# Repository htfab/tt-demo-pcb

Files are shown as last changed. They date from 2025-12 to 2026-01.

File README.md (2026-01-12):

# TinyTapeout Demo Board

Demo board for TinyTapeout ASICs

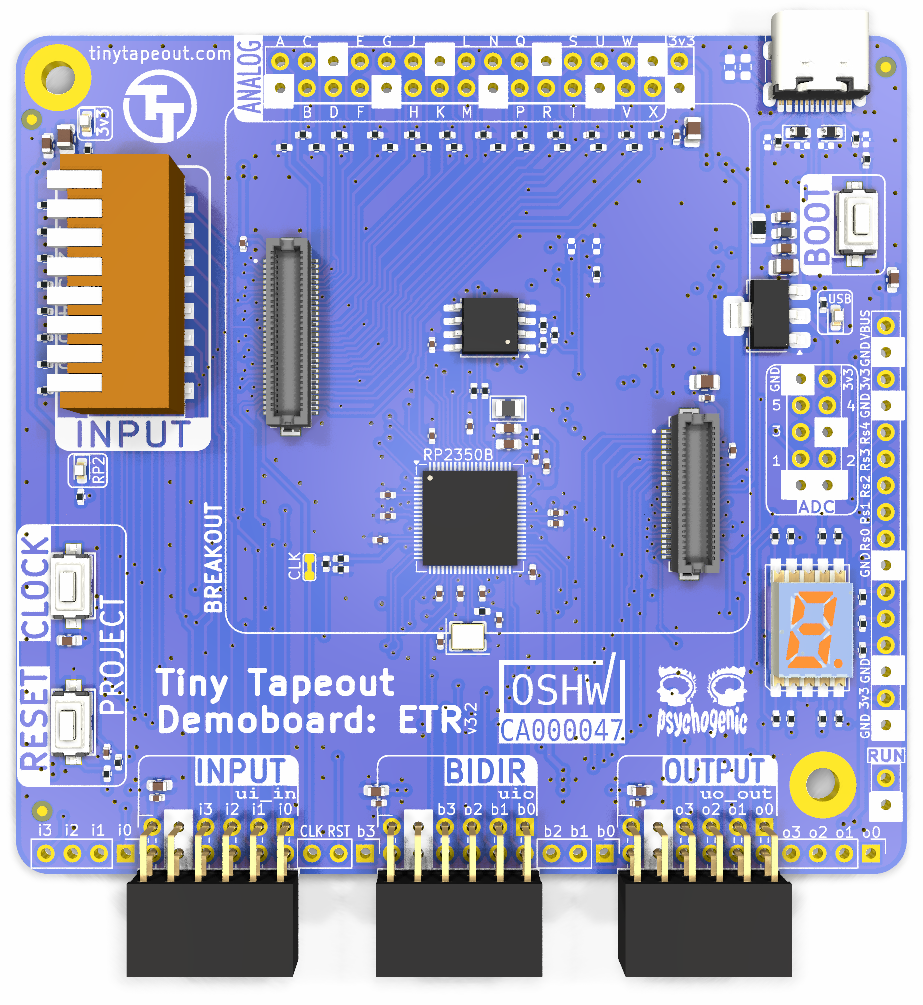
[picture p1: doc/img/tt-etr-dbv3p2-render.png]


These demonstration PCBs allow you to interact with [TinyTapeout](https://tinytapeout.com/) projects in 3 ways:

  * directly, using the input DIP switches and 7-segment display;
  * via breadboard or extension boards through PMODs; or
  * by interacting through the on-board RP2

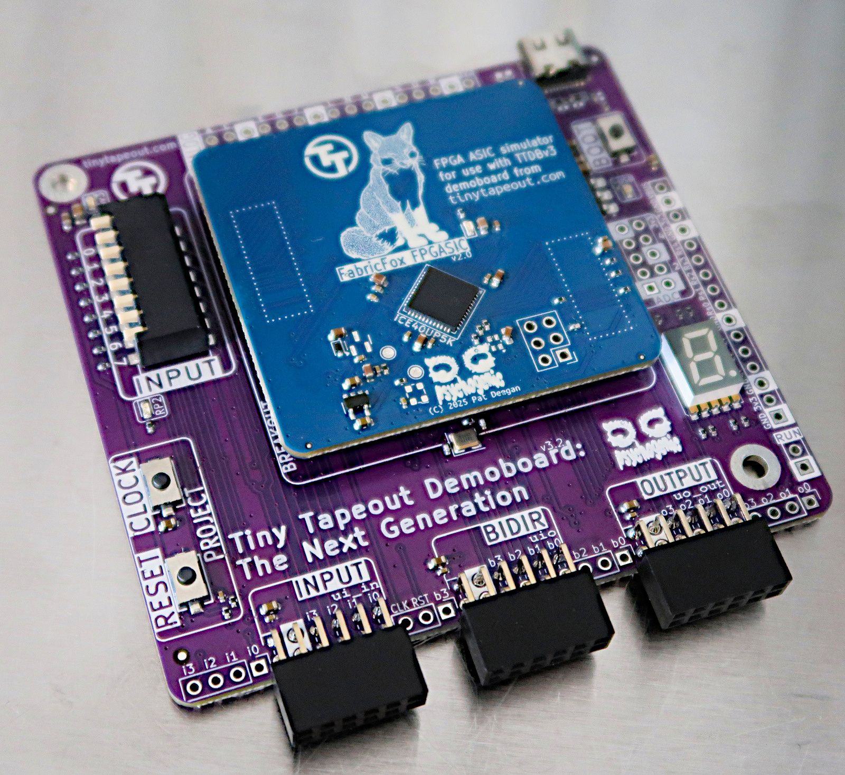
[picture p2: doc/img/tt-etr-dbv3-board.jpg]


In addition, since TT06, it is possible to create analog and mixed signal designs.  These signals are now available on a 100mil header directly on the demoboard

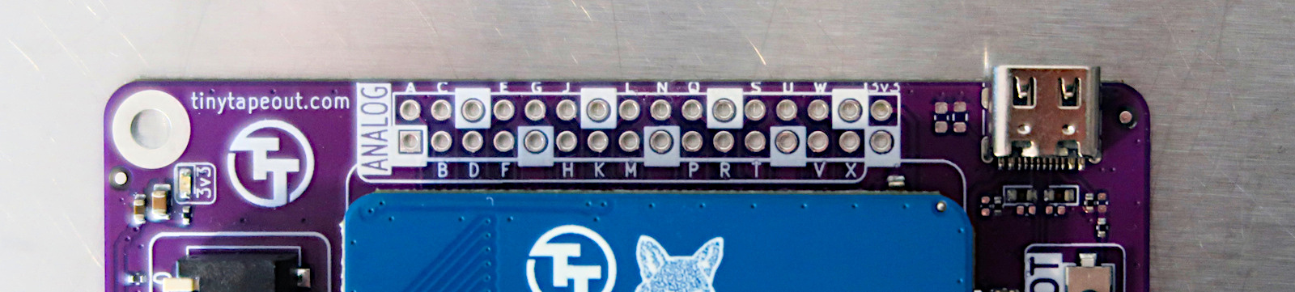
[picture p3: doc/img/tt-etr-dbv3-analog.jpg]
Breakout Board Analog IO


## Pinout Overview

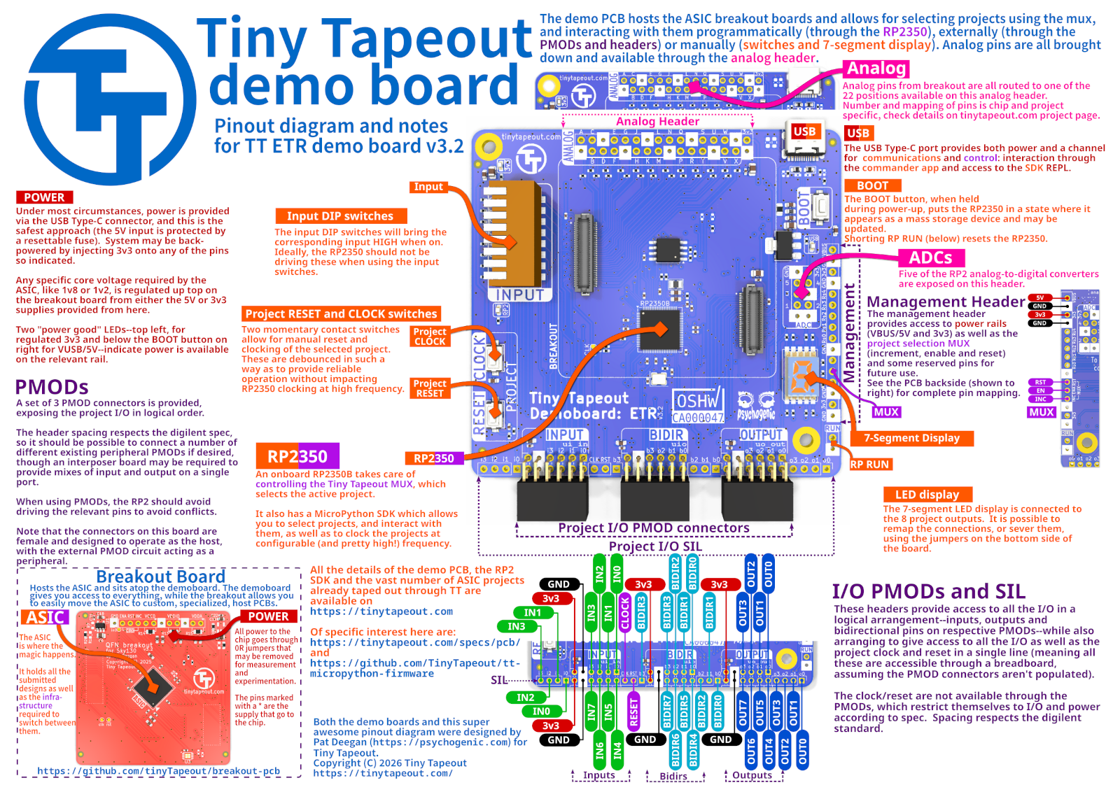
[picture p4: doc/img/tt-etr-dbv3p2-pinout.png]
Demoboard Pinout


### Previous Demoboard Versions

The details above are for the latest version of the demoboard.  To access leaflets and schematics for prior versions, see [here, in the historic documentation](doc/historic/README.md)

## Schematic and Function

The full schematic is available as a [PDF](doc/tt-etr-dbv3.pdf) but the gist of it is:

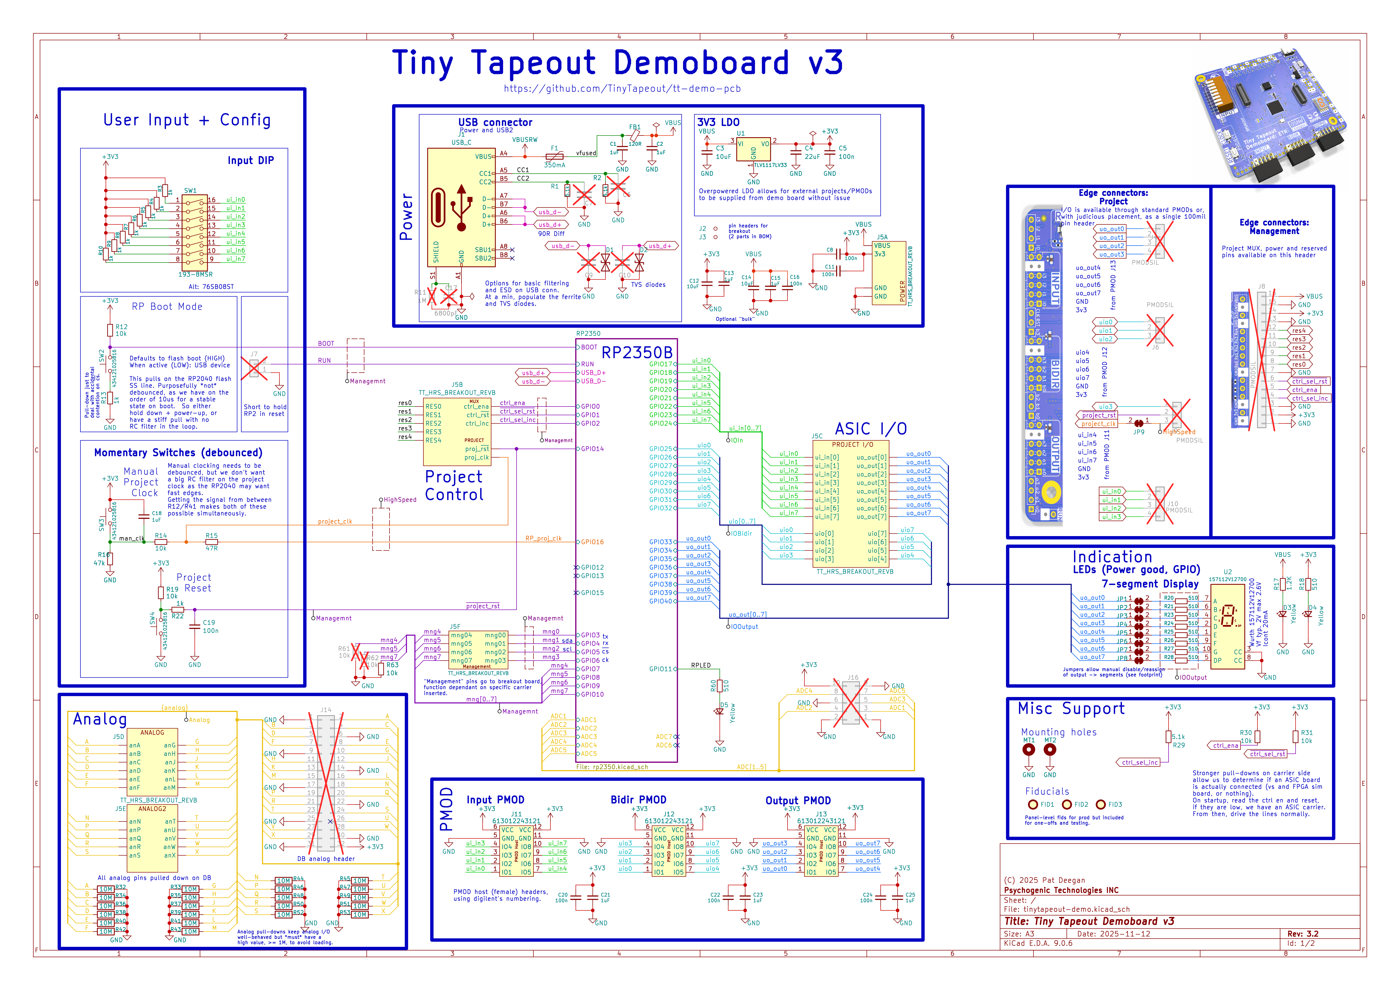
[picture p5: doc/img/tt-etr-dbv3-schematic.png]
Demoboard schematic


The RP2350 is responsible for selecting projects, by controlling the project MUX that's on the ASIC and, under most circumstances, providing the clock for the projects. It may, thereafter, interact with the design via it's connections to the input, output and bidirectional pins.

Another option is to use the various PMOD and pin headers to tie external circuitry to the design.  PMODs are provided in two varieties: straightforward I/O (where one PMOD is dedicated to each of in/out/bidir pins) and "standard" PMODs, that are mapped (mostly) according to specs to allow for SPI, I2C and UART extension boards to be plugged in (this assumes the project has been designed with this in mind, with I/O tasked accordingly). 

## PMODs

In addition with interfacing directly with projects via the RP2, extensions and interaction with the ASIC is possible through two sets of [PMODs](https://digilent.com/reference/_media/reference/pmod/pmod-interface-specification-1_2_0.pdf) on the demo boards.

The three on the bottom provide access to all the project I/O in a logical fashion, with inputs, bidirectional pins and outputs available on their own distinct headers.

IO PMODs

This is nice and orderly and gives you access to all the pins, but extension boards will often need to span at least two, and sometimes three, distinct headers.

For interfacing peripheral modules, an interposer board was created (TODO: display and link) to provide more standard mixes of input and output on single PMODs.

## RP2 Pinout

| TT Pin | RP2 Pin | I2C | SPI | UART |
| --- | --- | --- | --- | --- |
| reset | GPIO14 | | | |
| clock | GPIO16 | | | |
| ui_in[0]  | GPIO17 | | SPI0.cs  | |
| ui_in[1]  | GPIO18 | | SPI0.sck | |
| ui_in[2]  | GPIO19 | | SPI0.tx  | |
| ui_in[3]  | GPIO20 | | | UART1.tx |
| ui_in[4]  | GPIO21 | | SPI0.cs  | |
| ui_in[5]  | GPIO22 | | SPI0.sck | |
| ui_in[6]  | GPIO23 | | SPI0.tx  | UART1.rts|
| ui_in[7]  | GPIO24 | | | |
| uio[0] | GPIO25 | I2C0.scl | SPI1.cs  | UART1.rx |
| uio[1] | GPIO26 | I2C1.sda | SPI1.sck | UART1.cts|
| uio[2] | GPIO27 | I2C1.scl | SPI1.tx  | UART0.rts|
| uio[3] | GPIO28 | I2C0.sda | SPI1.rx  | UART0.tx |
| uio[4] | GPIO29 | I2C0.scl | SPI1.cs  | UART0.rx |
| uio[5] | GPIO30 | I2C1.sda | SPI1.sck | UART0.cts|
| uio[6] | GPIO31 | I2C1.scl | SPI1.tx  | UART0.rts|
| uio[7] | GPIO32 | | | |
| uo_out[0] | GPIO33 | | | UART0.rx |
| uo_out[1] | GPIO34 | | | UART0.cts|
| uo_out[2] | GPIO35 | | | |
| uo_out[3] | GPIO36 | | SPI0.rx  | |
| uo_out[4] | GPIO37 | | | UART1.rx |
| uo_out[5] | GPIO38 | | | UART1.cts|
| uo_out[6] | GPIO39 | | | |
| uo_out[7] | GPIO40 | | SPI0.rx  | |

## Removing the ASIC breakout board

With the [Hirose DF12 Series](https://www.hirose.com/product/series/DF12) connectors now in use, removing breakouts from demoboards should be much more straightforward:

* Insert a finger on opposite diagonals (top left, bottom right)
* Gently pry upwards until the breakout pops off.

There are markings indicating where the actually connectors are placed, on the underside, on the breakouts.

## License

* The PCB is licensed under the [Apache2 License](LICENSE)
* The documentation is licensed under the [CC0](https://creativecommons.org/publicdomain/zero/1.0/)
* OSHWA registration [CA000047](https://certification.oshwa.org/ca000047.html)

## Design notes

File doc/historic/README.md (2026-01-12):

# Schematics for prior demoboard versions

Though this schematic and layout data is all preserved in the commit history, for ease of reference the major milestones are accessible here, in reverse chronological order.

These should be the revisions actually sent to production for distribution.  The PDF includes the full schematic and the preview gives access to the most important information, as the RP2040 support sheet basically doesn't change.

## TT08

TT08 leaflet

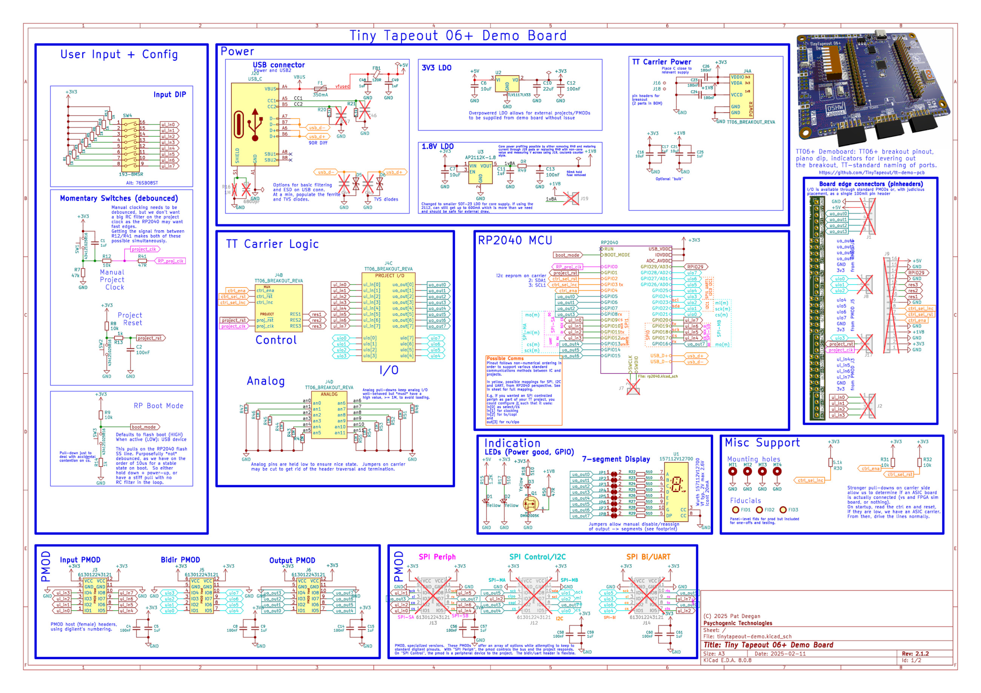
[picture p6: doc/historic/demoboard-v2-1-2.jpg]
TT08 schematic


[Version 2.1.2 schematic PDF](demoboard-v2-1-2.pdf)

Commit 028a51b1e5c6ff667839e42a188bc87d1115ad95 from Feb 25 19:59:02

## TT07

With the TT07 demoboard, signal naming was uniformized (using *ui_in*, *uo_out*).

TT07 leaflet

TT07 schematic

[Version 2.1.0 schematic PDF](demoboard-v2-1-0.pdf)

Commit a799acb3886b682b0f86c2f4d6155c08b5c505de from Wed Dec 11, 2024

## TT06

With TT06, the discreet MUX was dropped (along with Caravel support), the new much more comfortable piano switches were introduced for the input port.  The carrier format changed to break compatibility with prior boards, because of a new pinout and analog pin support.

TT06 leaflet

TT06 schematic

[Version 2.0.1 schematic PDF](demoboard-v2-0-1.pdf)

Commit 292760e1f727d805be471b7700232c9482b70ae3 from Thu Oct 10, 2024

## TT05

TT04/TT05 leaflet

TT05 schematic

[Version 1.2.3 schematic PDF](demoboard-v1-2-3.pdf)

Commit a88cbc08bdef564b16dc113f4489af65ff2ee86b from Tue Jun 11, 2024

## TT04

The TT04 demoboard introduced the RP2040, to handle selecting the projects through the ASIC project MUX.  TT04 boards also used a discreet multiplexer in order to provide enough pinnage to do all the things and have access to the caravel HK SPI safety net.

TT04 schematic

[Version 1.2.2 schematic PDF](demoboard-v1-2-2.pdf)

Commit cfdd80d7b79a667883998caccc05ebfad5d1b985 from Fri Apr 26, 2024

## TT02/TT03

Original demoboard used with TT02 and TT03.

TT03 leaflet

TT03 schematic

[TT03 demoboard schematic PDF](demoboard-mpw-mb1.pdf)

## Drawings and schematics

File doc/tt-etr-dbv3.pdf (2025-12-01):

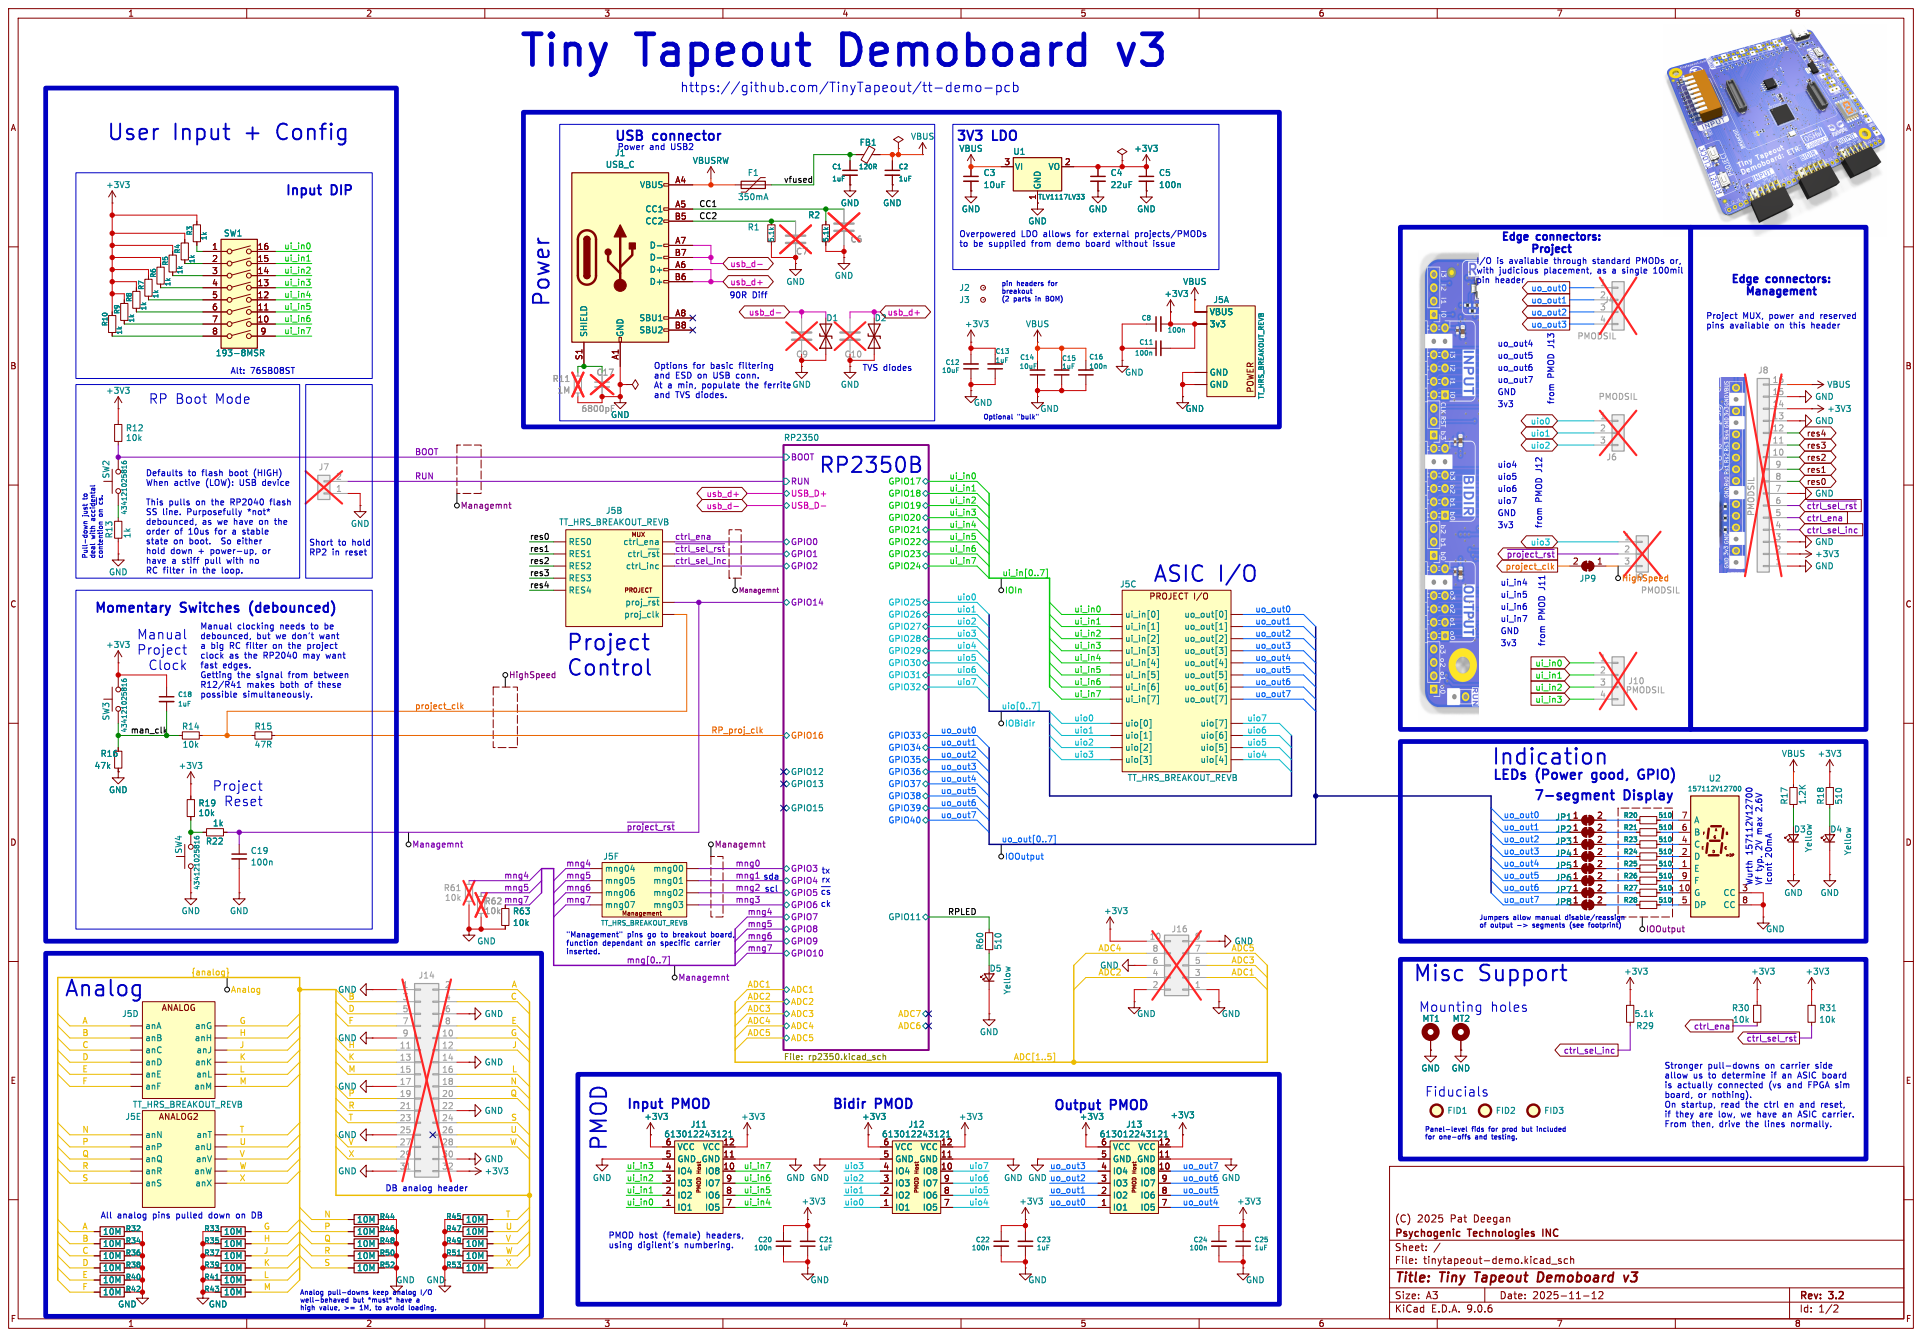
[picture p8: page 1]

Tiny Tapeout Demoboard v3 Pull-down just to deal with accidental contention on ~{cs}.

https://github.com/TinyTapeout/tt-demo-pcb
vfused

and TVS diodes. Input DIP

Edge connectors: Project from PMOD J12uio4
uo_out4

pin headers for breakout (2 parts in BOM)

Project MUX, power and reserved

Options for basic filtering

ck RP Boot Mode

order of 10us for a stable

Short to hold RP2 in reset

LEDs (Power good, GPIO)

Jumpers allow manual disable/reassign
Misc Support

if they are low, we have an ASIC carrier. From then, drive the lines normally.

Id: 1/2 Title: Tiny Tapeout Demoboard v3

high value, >= 1M, to avoid loading.

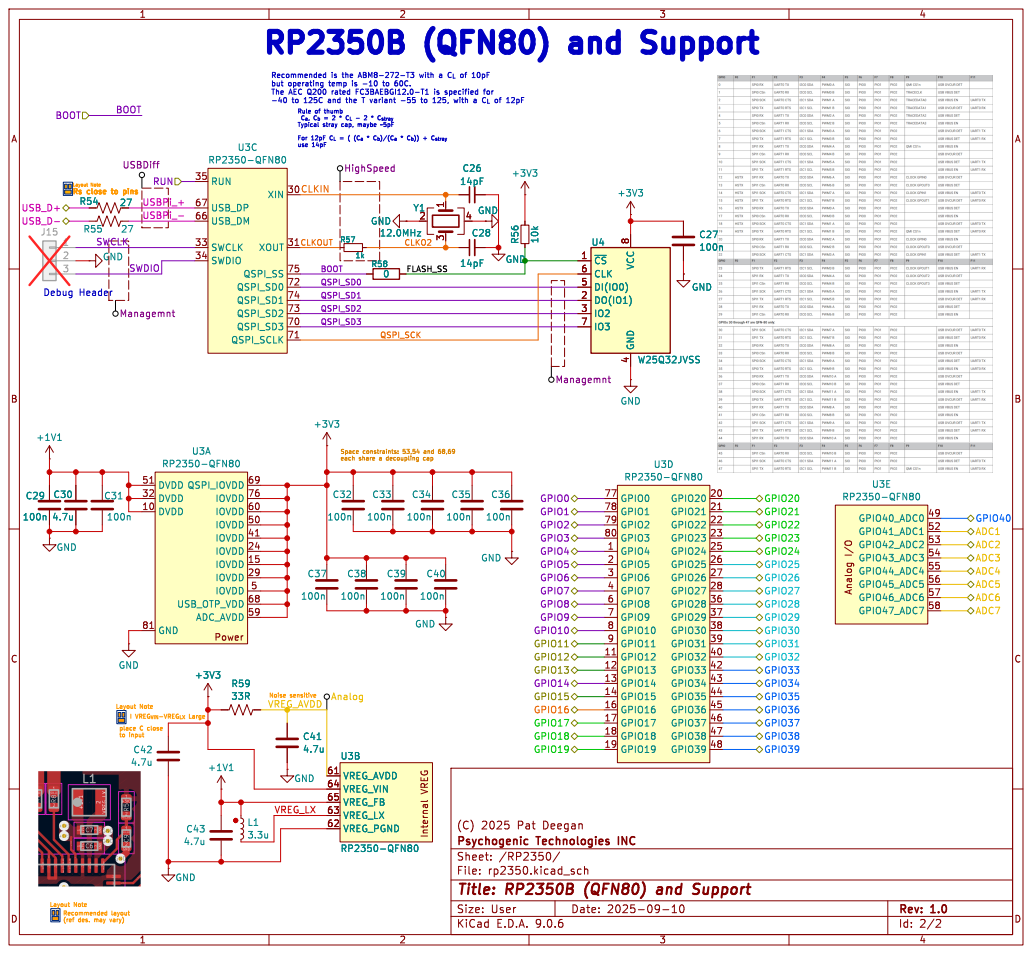
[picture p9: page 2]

Rule of thumb C_{a},C_{b}= 2 * C_{L}- 2 * C_{stray} Typical stray cap, maybe ~5pF

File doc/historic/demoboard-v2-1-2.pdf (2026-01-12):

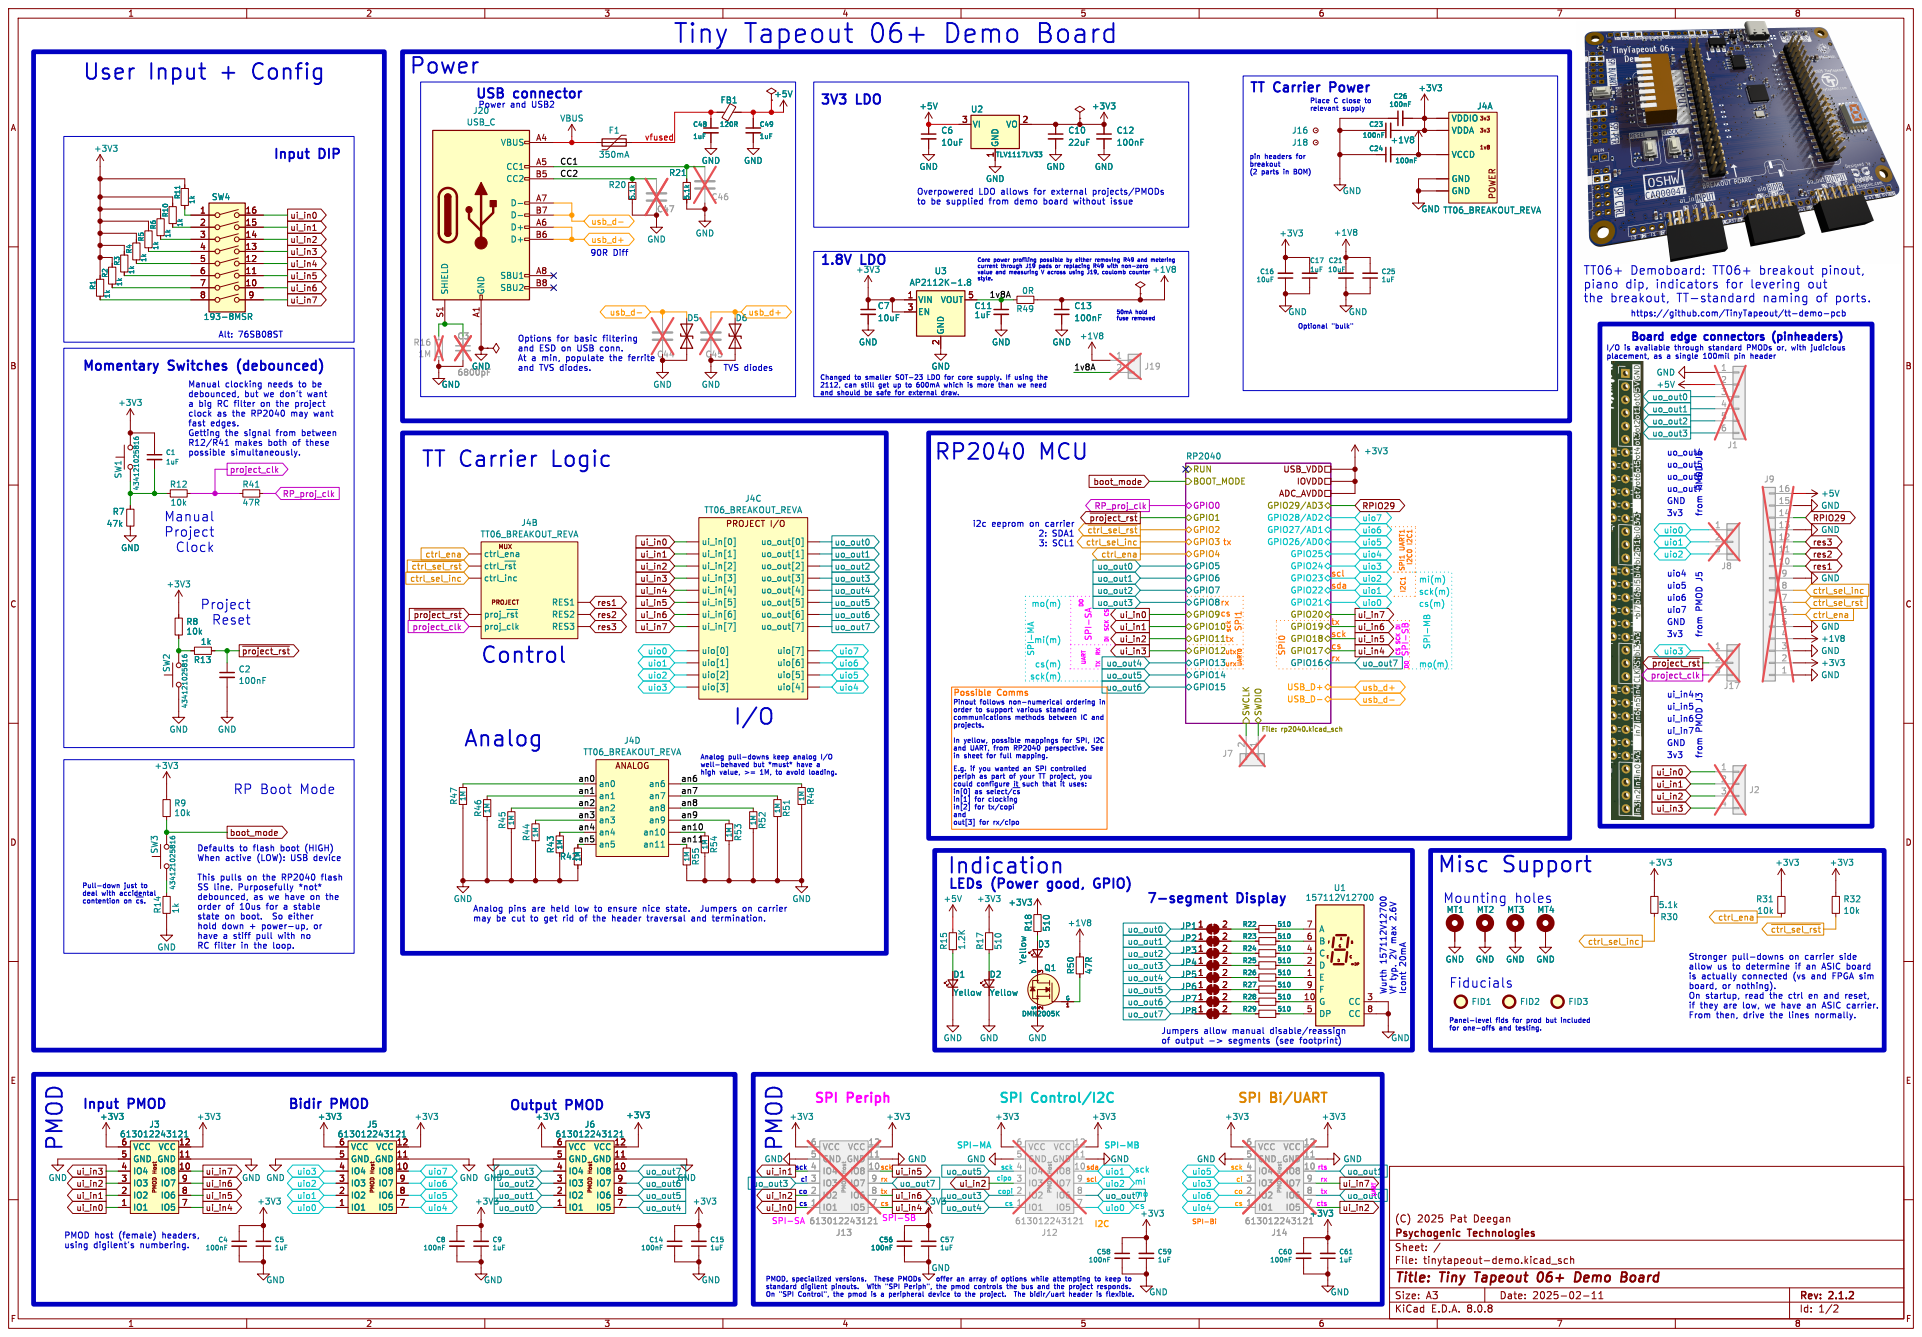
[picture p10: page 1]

tx Tiny Tapeout 06+ Demo Board

pin headers for breakout (2 parts in BOM)

2 EN 3 VOUT 5 GND GND GND GND

2112, can still get up to 600mA which is more than we need

tx TT Carrier Logic

mo(m) E.g. if you wanted an SPI controlled

in sheet for full mapping.

order of 10us for a stable

rts SPI Bi/UART

Id: 1/2 Title: Tiny Tapeout 06+ Demo Board

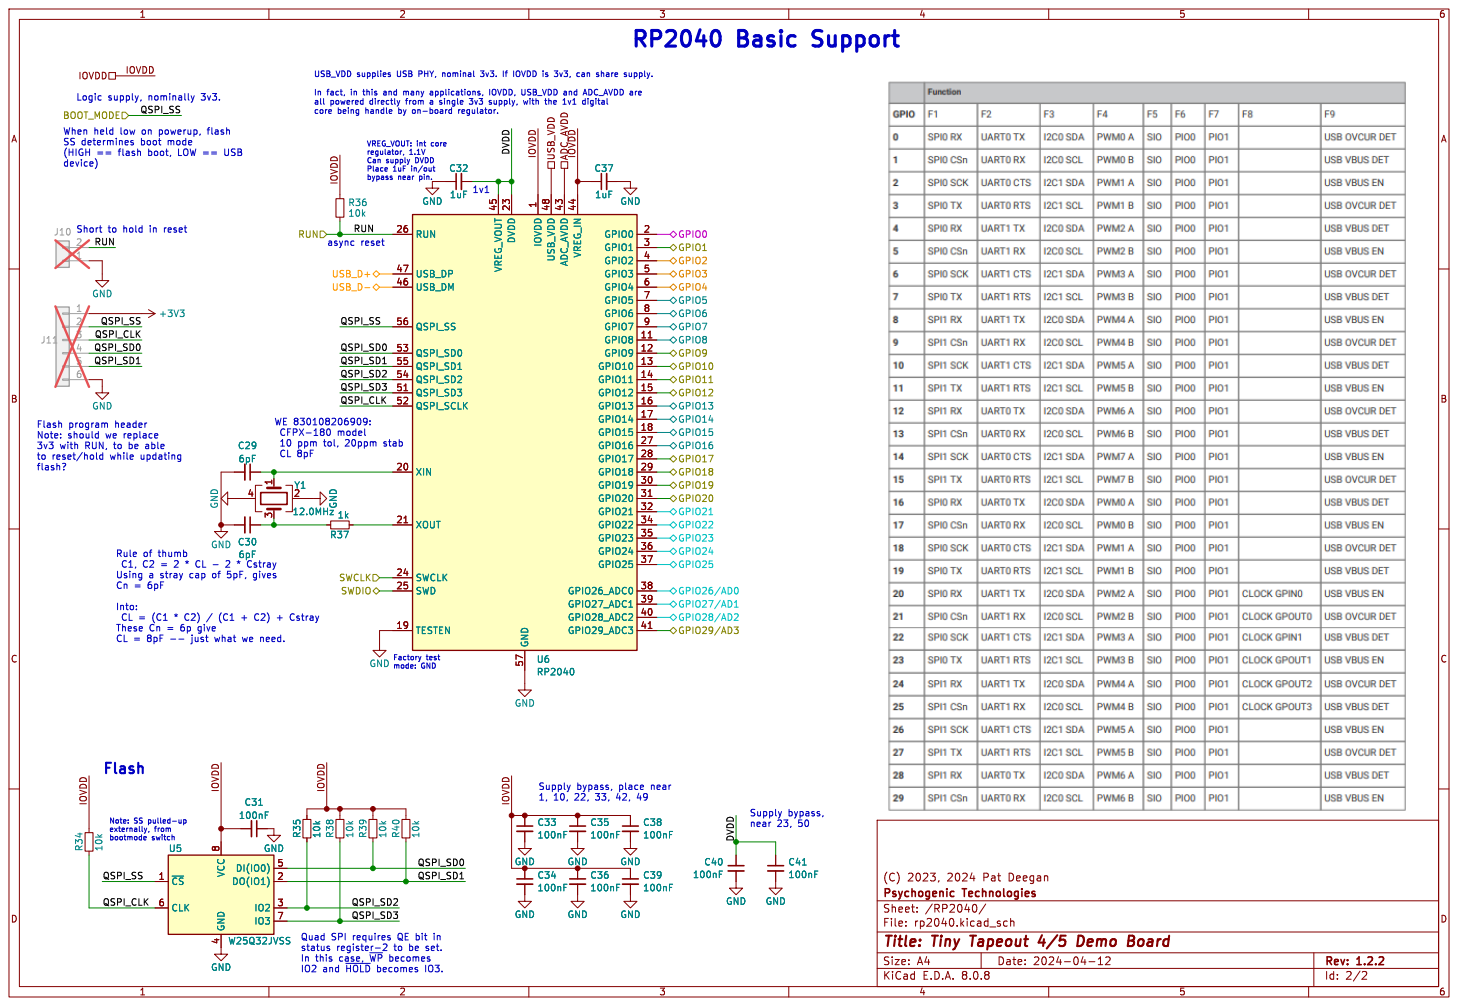
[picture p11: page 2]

async reset Quad SPI requires QE bit in

(HIGH == flash boot, LOW == USB
device)

1 GPIO8 11 GPIO9 12 GPIO10 13 GPIO11 14 GPIO12 15 GPIO13 16 GPIO14 17 GPIO15 18 TESTEN 19 GPIO0 2 XIN 20 XOUT 21 DVDD 23 SWCLK 24 SWD 25 RUN 26 GPIO16 27 GPIO17 28 GPIO18 29 GPIO1 3 GPIO19 30 GPIO20 31 GPIO21 32 GPIO22 34 GPIO23 35 GPIO24 36 GPIO25 37 GPIO26_ADC0 38 GPIO27_ADC1 39 GPIO2 4 GPIO28_ADC2 40 GPIO29_ADC3 41 ADC_AVDD 43 VREG_IN 44 VREG_VOUT 45 USB_DM 46 USB_DP 47 USB_VDD 48 GPIO3 5 QSPI_SD3 51 QSPI_SCLK 52 QSPI_SD0 53 QSPI_SD2 54 QSPI_SD1 55 QSPI_SS 56 GND 57 GPIO4 6 GPIO5 7 GPIO6 8 GPIO7 9 GND GND

1 GPIO8 11 GPIO9 12 GPIO10 13 GPIO11 14 GPIO12 15 GPIO13 16 GPIO14 17 GPIO15 18 TESTEN 19 GPIO0 2 XIN 20 XOUT 21 DVDD 23 SWCLK 24 SWD 25 RUN 26 GPIO16 27 GPIO17 28 GPIO18 29 GPIO1 3 GPIO19 30 GPIO20 31 GPIO21 32 GPIO22 34 GPIO23 35 GPIO24 36 GPIO25 37 GPIO26_ADC0 38 GPIO27_ADC1 39 GPIO2 4 GPIO28_ADC2 40 GPIO29_ADC3 41 ADC_AVDD 43 VREG_IN 44 VREG_VOUT 45 USB_DM 46 USB_DP 47 USB_VDD 48 GPIO3 5 QSPI_SD3 51 QSPI_SCLK 52 QSPI_SD0 53 QSPI_SD2 54 QSPI_SD1 55 QSPI_SS 56 GND 57 GPIO4 6 GPIO5 7 GPIO6 8 GPIO7 9 U6 RP2040 ~{CS} 1 DO(IO1) 2

Flash program header Note: should we replace

3v3 with RUN, to be able
flash?

Using a stray cap of 5pF, gives Cn = 6pF

Factory test mode: GND

Note: SS pulled-up

In this case, ~{WP}becomes
IO2 and ~{HOLD}becomes IO3.

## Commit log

2025-09-11 nextgen v3 PRELIMINARY
    [rp2040.kicad_sch, rp2350.kicad_sch, tinytapeout-demo.kicad_sch]
2025-12-01 v3.2 as prototyped
    [rp2350.kicad_sch, tinytapeout-demo.kicad_sch]
2026-01-12 pinout update, historic boards update
